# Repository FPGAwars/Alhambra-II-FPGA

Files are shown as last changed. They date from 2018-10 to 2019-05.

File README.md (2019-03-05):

# Alhambra II FPGA board
Open FPGA for makers

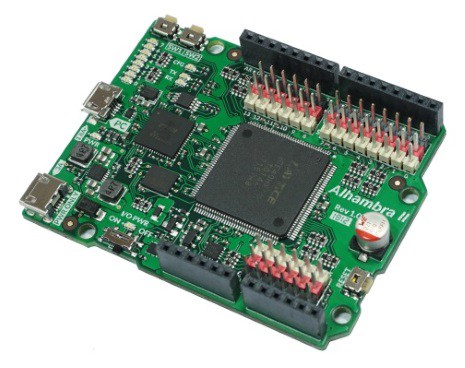
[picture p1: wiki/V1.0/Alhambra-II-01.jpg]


## Features

* iCE40HX4K (Lattice) FPGA development board (8K using opensource toolchain)
* Open hardware
* Compatible with the opensource [icestorm toolchain](Compatible with the opensource icestorm toolchain) and [Icestudio](https://github.com/FPGAwars/icestudio)
* Arduino like board: similar pinout than Arduino one
* You can Reuse most of available shields
* Control your robots / printbots from an FPGA
* FTDI 2232H USB device allows FPGA programming and UART interface to a PC
* ON/OFF electronic switch (turn off your mobile robot easily, switching on does not overload your USB port)
* 8 general purpose LEDs (user LEDs)
* 2 general purpose pushbuttons
* 32Mb flash memory for up to 30 bitstreams or user data
* 20 Input/output 3.3V (5V tolerant) pins
* All I/O pins include 200 ohms serial resistors for direct LED activation
* 4-Channels, 12 bits A/D converter
* Cold boot pins accessible from GPIO
* Switching regulators for high frequency processing at low power input
* 12 MHZ MEMS oscillator
* Reset pushbutton
* USB power supply, two connectors (up to 4.8A)
* Power pins and I/O pins allow permanent shortcircuit

## Documentation

[The proyect documentation is located in the wiki](https://github.com/FPGAwars/Alhambra-II-FPGA/wiki)

## Author

* [Eladio Delgado Mingorance](https://twitter.com/EladioDM)

## Credits

* Alhambra II V1.0 Board was derived from the [Icezum Alhambra V1.1 board](https://github.com/FPGAwars/icezum)

## License



Licensed under [Creative Commons Attribution-ShareAlike 4.0 International License](http://creativecommons.org/licenses/by-sa/4.0/)

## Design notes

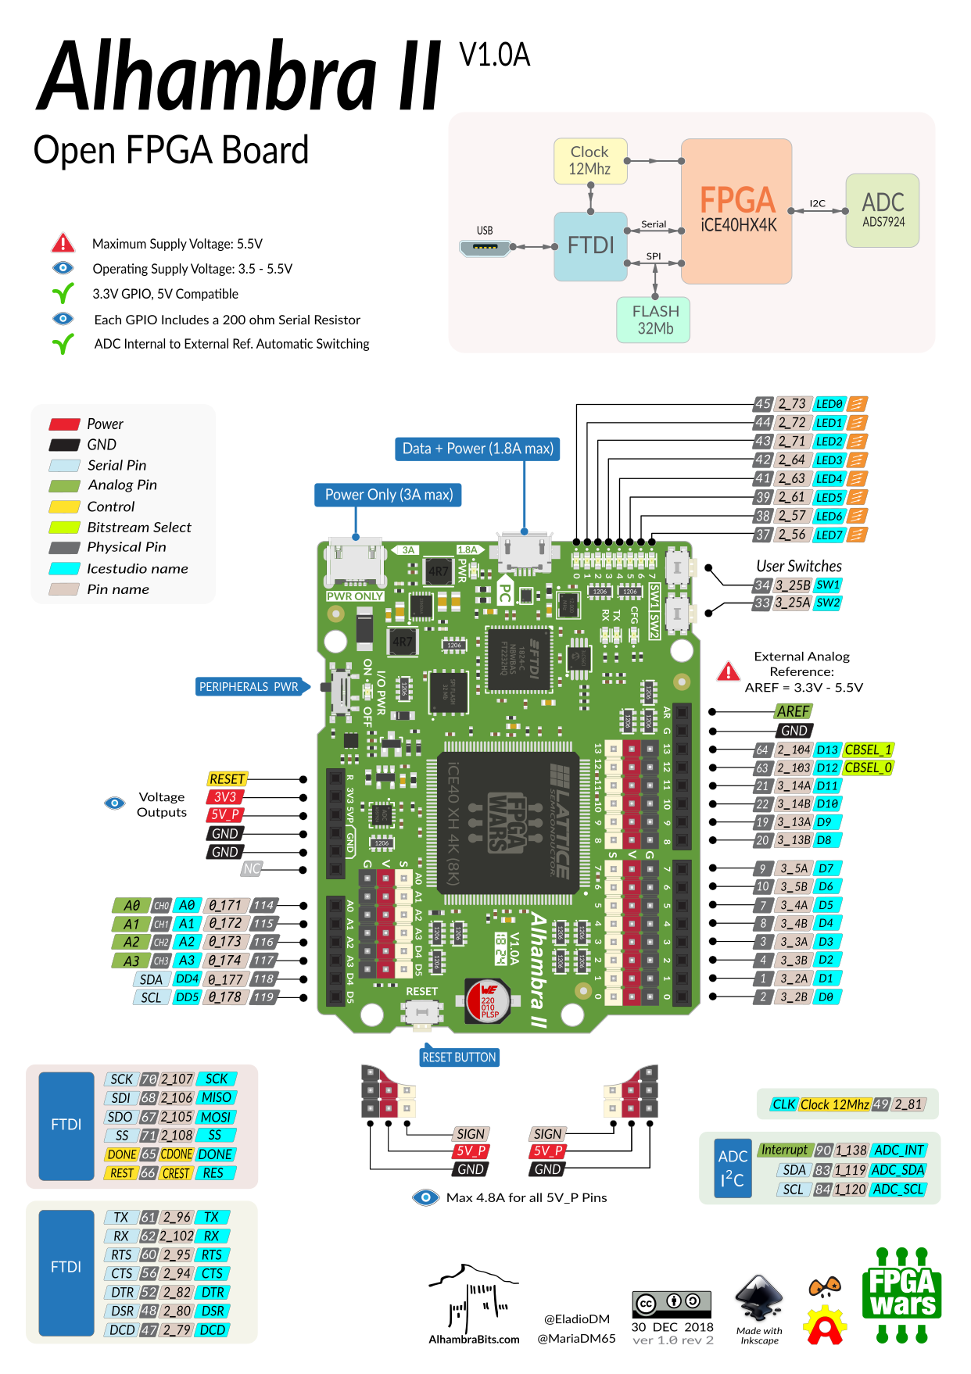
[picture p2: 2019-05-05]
doc/pinout/Alhambra II V1.0A - Pinout_v1.0_rev 2 - 150 dpi.png

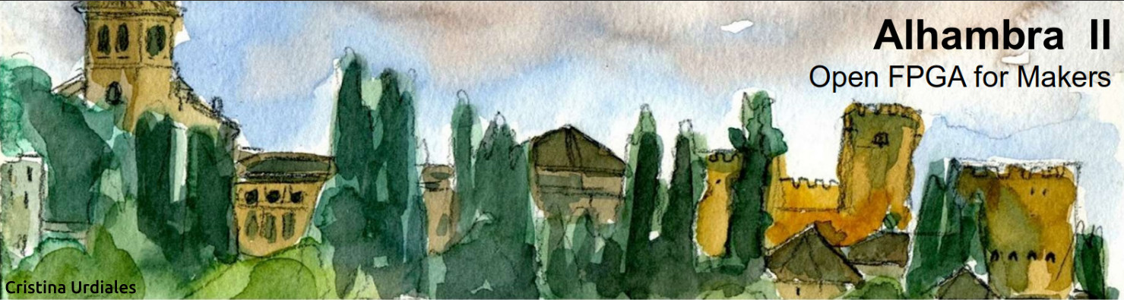
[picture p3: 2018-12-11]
wiki/V1.0/Alhambra-II-02.jpg

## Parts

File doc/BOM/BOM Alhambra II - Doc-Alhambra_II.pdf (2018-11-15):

BOM | Top Sheet
| Source Data From: | | Alhambra_II.PrjPcb
Project: | Alhambra_II.PrjPcb
PCB Version: | 1.0A
Variant: | None
Author: | Eladio Delgado Mingorance
Report Date: | 15/11/2018 9:33:17
Print Date: | 15-Nov-18 10:32:03 AM
# | Designator | Quantity | Description

1 | C1, C2, C4, C5, C7, C8, C9, C10, C11, C12, C13, C14, C15, C16, C17, C18, C20, C21, C22, C23, C25, C26, C27, C28, C29, C30, C32, C33, C34, C35, C36, C38, C39, C40, C46, C48, C49 | 37 | Capacitor SMD
2 3 | C3, C6, C19, C24, C31, C37, C43 | 7 | Capacitor SMD
| C41, C45, C47 | 3 | Capacitor SMD
4 5 | C42, C44 | 2 | Capacitor SMD
| C50 | 1 | Capacitor, Electrolytic, SMD
6 7 | D1, D5, D6 | 3 | Schottky Diode
| D2 | 1 | Protection, USB ESD
8 9 | D3 | 1 | Protection, Transient Suppression Diode
| D4 | 1 | Zener Diode
10 11 | FB1, FB2, FB3, FB4, FB5 | 5 | Ferrite Bead
| J1, J5 | 2 | Connector, 8 pin Socket Header 2.54mm
12 13 | J2, J6 | 2 | Connector, 6 pin Socket Header 2.54mm
| J3, J7 | 2 | Connector, 1x6 pin Header 2.54mm
14 15 | J4 | 1 | Connector, 1x8 pin Header 2.54mm
| J8, J12 | 2 | Connector, 1x6 pin Header 2.54mm
16 17 | J9, J13 | 2 | Connector, 1x6 pin Header 2.54mm
| J10 | 1 | Connector, 1x8 pin Header 2.54mm
18 19 | J11 | 1 | Connector, 1x8 pin Header 2.54mm
| J14 | 1 | Micro USB 2.0 SMT Type B Horizontal 5 Contacts WR-COM
20 21 | J15 | 1 | Micro USB 2.0 SMT Type B Horizontal 5 Contacts High Current WR-COM
| L1, L2 | 2 | Inductor SMD
22 23 | LD0, LD1, LD2, LD3, LD4, LD5, LD6, LD7, LD9 | 9 | LED
| LD8, LD10 | 2 | LED
24 25 | LD11, LD12 | 2 | LED
| Q1 | 1 | P-Channel MOSFET
26 27 | R1, R2, R19, R20, R21, R28, R29, R31, R32, R36, R37, R38, R39, R41, R42, R43 | 16 | Resistor, SMD
| R3, R23, R33, R47, R50 | 5 | Resistor, SMD
| R13, R30 | 11 | Resistor, Array 4x1
28 | R4, R5, R6, R7, R8, R9, R10, R11, R12,

29 | R14 | 1 | Resistor
30 31 | R15, R34, R35 | 3 | Resistor, Resistor, Array 4x1
| R16, R17, R25, R26, R27, R46 | 6 | Resistor, SMD
32 33 | R18, R22, R44, R45 | 4 | Resistor, SMD
| R24, R48, R49 | 3 | Resistor, SMD
34 35 | R40 | 1 | Resistor, SMD
| SW1, SW2, SW3 | 3 | Micro miniature pushbutton surface Switch
36 37 | SW4 | 1 | WS-SLSU 6.7x2.7 mm SMD Right Angled, boss design
| U1 | 1 | iCE40 HX4K Series FPGA Family, 3520 Logic Cells, 1.2 V Core, 80 K Embedded RAM Bits, 144-pin TQFP, Pb-Free, Tray
38 39 | U2 | 1 | NOR Flash Memory, serial
| U3 | 1 | Dual High Speed USB to Multipurpose UART/FIFO IC
40 41 | U4 | 1 | EEPROM, 2K Microwire Compatible Serial, 8 or 16 bit word size, 2.5-5.5 Vcc range
| U5 | 1 | Oscillator, Low-Power CMOS, 4 pin, 1.8-3.3V
42 43 | U6 | 1 | LDO Regulator, 5pin, SOT-23
| U7 | 1 | ADC Converter, 12-Bit, 4-Ch, I2C
44 45 | U8 | 1 | Dual Step-Down DC/DC converter 1A, 1.5 MHz
| U9 | 1 | Voltage supervisor, Reset active high, 200ms
Total Quantity | 155 | Notes

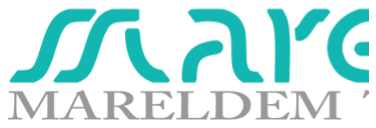
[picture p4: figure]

Value | Footprint | OrderingCode | Manufacturer
100nF ±10% 16V | C0402 | C0402C104K4RAC | Kemet
10uF ±10% 10V | C0603 | GRM188R61A106KE69D | Murata
10uF ±10% 10V | C0805_1.25_HD | LMK212ABJ106KG | Taiyo Yuden
100pF ±5% 25V | C0402 | 885012005046 | WE
220uF 10V | C_POL_6.3x5.8_WE | 875105244013 | WE
200mA 30V | SOD523 | RB520S30T1G | On Semiconductor
| SOT563 | 82400152 | Würth
| DO-214AC-SMA_Unidir | 824500500 | WE
3,6V | DO-219AC | PLZ3V6A | Vishay
330R 0,080R 1700 mA | L0603 | BLM18KG331SN1 | Murata
8 PIH | 1x8 Socket Header THT 2.54mm PIH | SSW-108-01-T-S | Samtec
6 PIH | 1x6 Socket Header THT 2.54mm PIH | SSW-106-01-T-S | Samtec
| 1x6 Pin Header 2.54 WHITE PIH | HTSW-106-07-T-S-NATURAL | Samtec
| 1x8 Pin Header 2.54 WHITE PIH | HTSW-108-07-T-S-NATURAL | Samtec
| 1x6 Pin Header 2.54 RED PIH | HTSW-106-07-T-S-RED | Samtec
| 1x6 Pin Header 2.54 BLACK PIH | HTSW-106-07-T-S-BLACK | Samtec
| 1x8 Pin Header 2.54 RED PIH | HTSW-108-07-T-S-RED | Samtec
| 1x8 Pin Header 2.54 BLACK PIH | HTSW-108-07-T-S-BLACK | Samtec
| 629105136821 | 629105136821 | WE
| 629105150521 | 629105150521 | WE
4,7uH 1,7A | 4018_WE_LQS_4R7 | 74404042047 | WE
Green | LED0603 | 150 060 VS7 5000 | WE
Yellow | LED0603 | 150 060 YS7 5000 | WE
Blue | LED0603 | 150 060 BS7 5000 | WE
| U-DFN2020-6 | DMP1005UFDF-7 | Diodes Incorporated
10k ±1% 0.063W | R0402 | CRCW040210K0FK | Vishay
1k ±5% 0.063W | R0402 | CRCW04021K00JN | Vishay
100R 5% 0,0625W, 100R ±5% 0,0625W | 4xArray_1206_Convex | YC164-JR-07100RL | Yageo

10K ±5% 0,0625W | 4xArray_1206_Convex | YC164-JR-0710KL | Yageo
470R ±5% 0,0625W, 470R 5% 0,0625W | 4xArray_1206_Convex | YC164-JR-07470RL | Yageo
100R ±5% 0.063W | R0402 | CRCW0402100RJN | Vishay
2k2 ±5% 0.063W | R0402 | CRCW04022K20JN | Vishay
12k ±1% 0.063W | R0402 | CRCW040212K0FK | Vishay
47k ±1% 0.063W | R0402 | CRCW040247K0FK | Vishay
| 4363x30458xx | 436353045816 | WE
| 450404015514 | 450404015514 | WE
| TQFP-144_HX4K_FPGAwars | iCE40HX4K-TQ144 | Lattice
32Mb | DFN-8 6x5mm | N25Q032A13EF640E | Micron
| FTDI_QFN-64 | FT2232HQ-REEL | FTDI
2Kb | MSOP8 | 93LC56CT-I/MS | Microchip
12MHz | OSC 3.2x2.5 | DSC1001CL2-012.0000 | Microchip
| SOT23-5_M | NCP114BSN330T1G | ON Semiconductor
| QFN16 | ADS7924IRTER | Texas Instruments
| WDFN_12_3x3 | PAM2306AYPKB | Diodes
2,93V | SOT23-3 | APX810-29SAG-7 | Diodes Incorporated

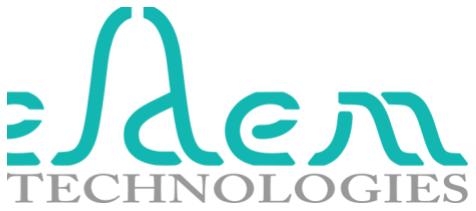
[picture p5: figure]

Supplier | Price (€) | Cost (€)
| 0,05 | 1,85
| 0,027 | 0,189
| 0,03 | 0,09
| 0,007 | 0,014
| 0,3 | 0,3
| 0,017 | 0,051
Würth | 0,1 | 0,1
| 0,108 | 0,108
| 0,07 | 0,07
| 0,021 | 0,105
Samtec | 0,438 | 0,876
Samtec | 0,381 | 0,762
Samtec | 0,26 | 0,52
Samtec | 0,35 | 0,35
Samtec | 0,26 | 0,52
Samtec | 0,26 | 0,52
Samtec | 0,35 | 0,35
Samtec | 0,35 | 0,35
WE | 0,26 | 0,26
WE | 0,58 | 0,58
WE | 0,128 | 0,256
| 0,07 | 0,63
| 0,07 | 0,14
| 0,09 | 0,18
| 0,16 | 0,16
| 0,006 | 0,096
| 0,003 | 0,015
| 0,006 | 0,066

0,006 | 0,006
| 0,006 | 0,018
| 0,003 | 0,018
| 0,003 | 0,012
| 0,006 | 0,018
| 0,006 | 0,006
WE | 0,2 | 0,6
WE | 0,27 | 0,27
| 6 | 6
Silica | 0,9 | 0,9
Silica | 3,45 | 3,45
Silica | 0,24 | 0,24
| 0,61 | 0,61
| 0,07 | 0,07
Silica | 1,35 | 1,35
RS | 0,32 | 0,32
Silica | 0,1 | 0,1
| Total Cost | 23,50

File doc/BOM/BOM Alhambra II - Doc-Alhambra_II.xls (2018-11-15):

 | BOM |  | Top Sheet
 | Source Data From: |  | Alhambra_II.PrjPcb
 | Project: |  | Alhambra_II.PrjPcb
 | PCB Version: |  | 1.0A
 | Variant: |  | None
 | Author: |  | Eladio Delgado Mingorance
 | Report Date: | 15/11/2018 | 9:33:17
 | Print Date: | 2018-11-15 | 9:35:09
# | Designator | Quantity | Description | Value | Footprint | OrderingCode | Manufacturer | Supplier | Price (€) | Cost (€)
1 | C1, C2, C4, C5, C7, C8, C9, C10, C11, C12, C13, C14, C15, C16, C17, C18, C20, C21, C22, C23, C25, C26, C27, C28, C29, C30, C32, C33, C34, C35, C36, C38, C39, C40, C46, C48, C49 | 37 | Capacitor SMD | 100nF ±10% 16V | C0402 | C0402C104K4RAC | Kemet |  | 0,05 | 1.85
2 | C3, C6, C19, C24, C31, C37, C43 | 7 | Capacitor SMD | 10uF ±10% 10V | C0603 | GRM188R61A106KE69D | Murata |  | 0,027 | 0.189
3 | C41, C45, C47 | 3 | Capacitor SMD | 10uF ±10% 10V | C0805_1.25_HD | LMK212ABJ106KG | Taiyo Yuden |  | 0,03 | 0.09
4 | C42, C44 | 2 | Capacitor SMD | 100pF ±5% 25V | C0402 | 885012005046 | WE |  | 0,007 | 0.014
5 | C50 | 1 | Capacitor, Electrolytic, SMD | 220uF 10V | C_POL_6.3x5.8_WE | 875105244013 | WE |  | 0,3 | 0.3
6 | D1, D5, D6 | 3 | Schottky Diode | 200mA 30V | SOD523 | RB520S30T1G | On Semiconductor |  | 0,017 | 0.051
7 | D2 | 1 | Protection, USB ESD |  | SOT563 | 82400152 | Würth | Würth | 0,1 | 0.1
8 | D3 | 1 | Protection, Transient Suppression Diode |  | DO-214AC-SMA_Unidir | 824500500 | WE |  | 0,108 | 0.108
9 | D4 | 1 | Zener Diode | 3,6V | DO-219AC | PLZ3V6A | Vishay |  | 0,07 | 0.07
10 | FB1, FB2, FB3, FB4, FB5 | 5 | Ferrite Bead | 330R 0,080R 1700 mA | L0603 | BLM18KG331SN1 | Murata |  | 0,021 | 0.105
11 | J1, J5 | 2 | Connector, 8 pin Socket Header 2.54mm | 8 PIH | 1x8 Socket Header THT 2.54mm PIH | SSW-108-01-T-S | Samtec | Samtec | 0,438 | 0.876
12 | J2, J6 | 2 | Connector, 6 pin Socket Header 2.54mm | 6 PIH | 1x6 Socket Header THT 2.54mm PIH | SSW-106-01-T-S | Samtec | Samtec | 0,381 | 0.762
13 | J3, J7 | 2 | Connector, 1x6 pin Header 2.54mm |  | 1x6 Pin Header 2.54 WHITE PIH | HTSW-106-07-T-S-NATURAL | Samtec | Samtec | 0,26 | 0.52
14 | J4 | 1 | Connector, 1x8 pin Header 2.54mm |  | 1x8 Pin Header 2.54 WHITE PIH | HTSW-108-07-T-S-NATURAL | Samtec | Samtec | 0,35 | 0.35
15 | J8, J12 | 2 | Connector, 1x6 pin Header 2.54mm |  | 1x6 Pin Header 2.54 RED PIH | HTSW-106-07-T-S-RED | Samtec | Samtec | 0,26 | 0.52
16 | J9, J13 | 2 | Connector, 1x6 pin Header 2.54mm |  | 1x6 Pin Header 2.54 BLACK PIH | HTSW-106-07-T-S-BLACK | Samtec | Samtec | 0,26 | 0.52
17 | J10 | 1 | Connector, 1x8 pin Header 2.54mm |  | 1x8 Pin Header 2.54 RED PIH | HTSW-108-07-T-S-RED | Samtec | Samtec | 0,35 | 0.35
18 | J11 | 1 | Connector, 1x8 pin Header 2.54mm |  | 1x8 Pin Header 2.54 BLACK PIH | HTSW-108-07-T-S-BLACK | Samtec | Samtec | 0,35 | 0.35
19 | J14 | 1 | Micro USB 2.0 SMT Type B Horizontal 5 Contacts WR-COM |  | 629105136821 | 629105136821 | WE | WE | 0,26 | 0.26
20 | J15 | 1 | Micro USB 2.0 SMT Type B Horizontal 5 Contacts High Current WR-COM |  | 629105150521 | 629105150521 | WE | WE | 0,58 | 0.58
21 | L1, L2 | 2 | Inductor SMD | 4,7uH 1,7A | 4018_WE_LQS_4R7 | 74404042047 | WE | WE | 0,128 | 0.256
22 | LD0, LD1, LD2, LD3, LD4, LD5, LD6, LD7, LD9 | 9 | LED | Green | LED0603 | 150 060 VS7 5000 | WE |  | 0,07 | 0.63
23 | LD8, LD10 | 2 | LED | Yellow | LED0603 | 150 060 YS7 5000 | WE |  | 0,07 | 0.14
24 | LD11, LD12 | 2 | LED | Blue | LED0603 | 150 060 BS7 5000 | WE |  | 0,09 | 0.18
25 | Q1 | 1 | P-Channel MOSFET |  | U-DFN2020-6 | DMP1005UFDF-7 | Diodes Incorporated |  | 0,16 | 0.16
26 | R1, R2, R19, R20, R21, R28, R29, R31, R32, R36, R37, R38, R39, R41, R42, R43 | 16 | Resistor, SMD | 10k ±1% 0.063W | R0402 | CRCW040210K0FK | Vishay |  | 0,006 | 0.096
27 | R3, R23, R33, R47, R50 | 5 | Resistor, SMD | 1k ±5% 0.063W | R0402 | CRCW04021K00JN | Vishay |  | 0,003 | 0.015
28 | R4, R5, R6, R7, R8, R9, R10, R11, R12, R13, R30 | 11 | Resistor, Array 4x1 | 100R 5% 0,0625W, 100R ±5% 0,0625W | 4xArray_1206_Convex | YC164-JR-07100RL | Yageo |  | 0,006 | 0.066
29 | R14 | 1 | Resistor | 10K ±5% 0,0625W | 4xArray_1206_Convex | YC164-JR-0710KL | Yageo |  | 0,006 | 0.006
30 | R15, R34, R35 | 3 | Resistor, Resistor, Array 4x1 | 470R ±5% 0,0625W, 470R 5% 0,0625W | 4xArray_1206_Convex | YC164-JR-07470RL | Yageo |  | 0,006 | 0.018
31 | R16, R17, R25, R26, R27, R46 | 6 | Resistor, SMD | 100R ±5% 0.063W | R0402 | CRCW0402100RJN | Vishay |  | 0,003 | 0.018
32 | R18, R22, R44, R45 | 4 | Resistor, SMD | 2k2 ±5% 0.063W | R0402 | CRCW04022K20JN | Vishay |  | 0,003 | 0.012
33 | R24, R48, R49 | 3 | Resistor, SMD | 12k ±1% 0.063W | R0402 | CRCW040212K0FK | Vishay |  | 0,006 | 0.018
34 | R40 | 1 | Resistor, SMD | 47k ±1% 0.063W | R0402 | CRCW040247K0FK | Vishay |  | 0,006 | 0.006
35 | SW1, SW2, SW3 | 3 | Micro miniature pushbutton surface Switch |  | 4363x30458xx | 436353045816 | WE | WE | 0,2 | 0.6
36 | SW4 | 1 | WS-SLSU 6.7x2.7 mm SMD Right Angled, boss design |  | 450404015514 | 450404015514 | WE | WE | 0,27 | 0.27
37 | U1 | 1 | iCE40 HX4K Series FPGA Family, 3520 Logic Cells, 1.2 V Core, 80 K Embedded RAM Bits, 144-pin TQFP, Pb-Free, Tray |  | TQFP-144_HX4K_FPGAwars | iCE40HX4K-TQ144 | Lattice |  | 6 | 6
38 | U2 | 1 | NOR Flash Memory, serial | 32Mb | DFN-8 6x5mm | N25Q032A13EF640E | Micron | Silica | 0,9 | 0.9
39 | U3 | 1 | Dual High Speed USB to Multipurpose UART/FIFO IC |  | FTDI_QFN-64 | FT2232HQ-REEL | FTDI | Silica | 3,45 | 3.45
40 | U4 | 1 | EEPROM, 2K Microwire Compatible Serial, 8 or 16 bit word size, 2.5-5.5 Vcc range | 2Kb | MSOP8 | 93LC56CT-I/MS | Microchip | Silica | 0,24 | 0.24
41 | U5 | 1 | Oscillator, Low-Power CMOS, 4 pin, 1.8-3.3V | 12MHz | OSC 3.2x2.5 | DSC1001CL2-012.0000 | Microchip |  | 0,61 | 0.61
42 | U6 | 1 | LDO Regulator, 5pin, SOT-23 |  | SOT23-5_M | NCP114BSN330T1G | ON Semiconductor |  | 0,07 | 0.07
43 | U7 | 1 | ADC Converter, 12-Bit, 4-Ch, I2C |  | QFN16 | ADS7924IRTER | Texas Instruments | Silica | 1,35 | 1.35
44 | U8 | 1 | Dual Step-Down DC/DC converter 1A, 1.5 MHz |  | WDFN_12_3x3 | PAM2306AYPKB | Diodes | RS | 0,32 | 0.32
45 | U9 | 1 | Voltage supervisor, Reset active high, 200ms | 2,93V | SOT23-3 | APX810-29SAG-7 | Diodes Incorporated | Silica | 0,1 | 0.1
 | Total Quantity | 155 | Notes |  |  |  |  |  | Total Cost | 23.50

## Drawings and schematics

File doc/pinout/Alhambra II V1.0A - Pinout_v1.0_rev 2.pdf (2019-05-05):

# Alhambra II

# FTDI

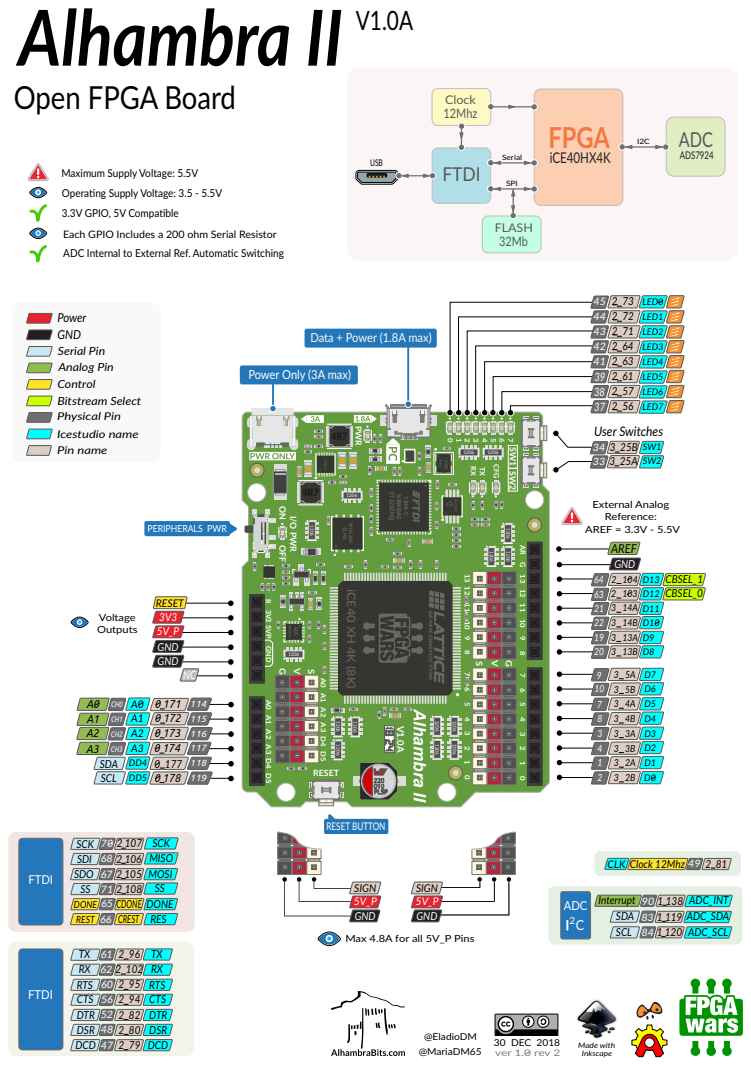
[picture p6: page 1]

Maximum Supply Voltage: 5.5V
Operang Supply Voltage: 3.5 - 5.5V
3.3V GPIO, 5V Compable
Each GPIO Includes a 200 ohm Serial Resistor
ADC Internal to External Ref. Automac Switching

Max 4.8A for all 5V_P Pins

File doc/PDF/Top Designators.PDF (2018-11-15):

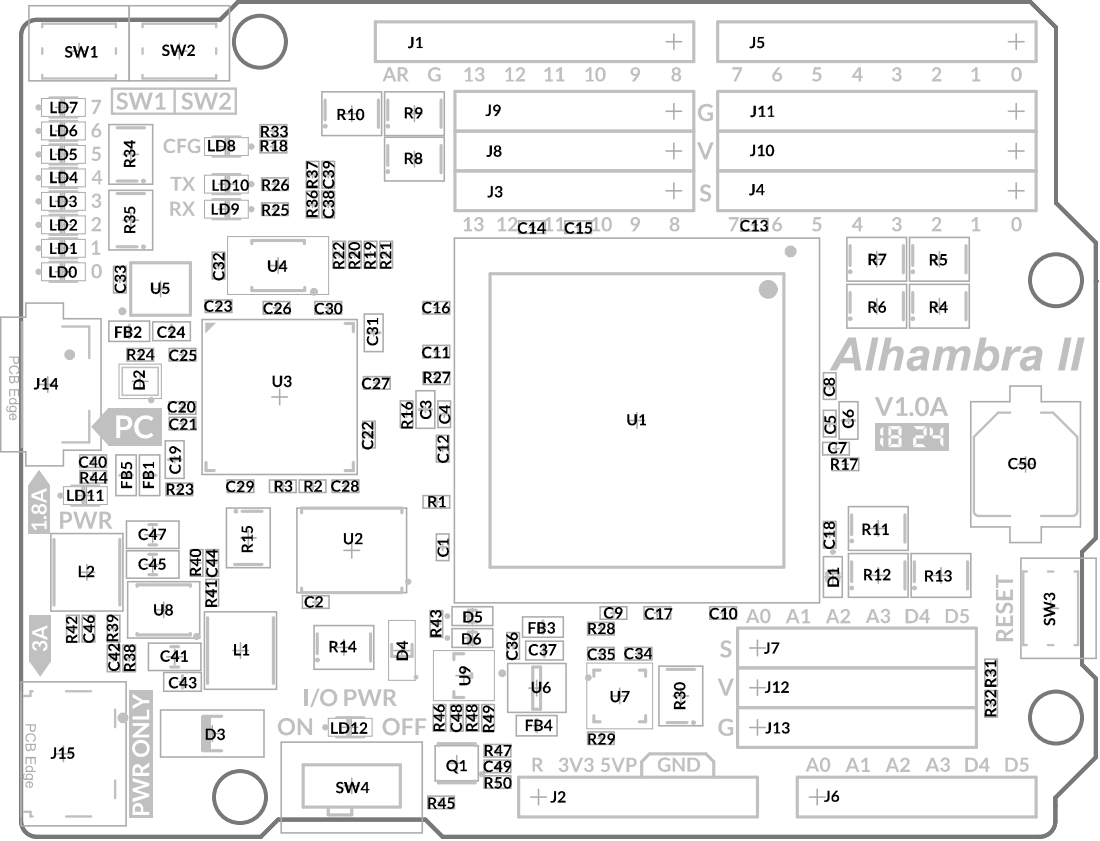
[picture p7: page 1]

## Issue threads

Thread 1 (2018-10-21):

Firmware update/upload (FPGArduino)

drtrigon, 2018-10-21:
As mentioned in https://github.com/cliffordwolf/picorv32/issues/92; "The firmware should be uploaded in the flash memory using iceprog, outside of icestudio. In future versión we will integrate it into icestudio as well".

What about support for FPGArduino (see http://www.nxlab.fer.hr/fpgarduino/)? That would allow to compile and upload code via Arduino IDE:
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

drtrigon, 2018-10-28:
https://github.com/f32c/arduino/issues/32

Closed 2018-10-28.

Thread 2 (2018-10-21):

Enable 32 bit GPIO input

drtrigon, 2018-10-21:
Based on https://github.com/cliffordwolf/picorv32/issues/92 I enhanced the design to 32 output pins as shown here (renamed leds[7:0] to outp[31:0]):
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
How to add a control register that allows to switch single bits from output to input? How to add input pin functionality?

drtrigon, 2018-10-28:
See https://github.com/cliffordwolf/picorv32/issues/96#issuecomment-433698391.

> May be you can integrate this example into the repo as well in order to be helpful to others too?
>
> However one question remains; Can you explain to me how to use the tri-state block? I placed and wired it - verification was ok but no bitstream could be generated, the result was an error.

Closed 2018-10-28.

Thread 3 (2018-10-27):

Alhambra ADC example

drtrigon, 2018-10-27:
Is an ADC example for Alhambra 2 available? May be one using picorv32?

I only found one for "MCP300x A/D controller (SPI master)" but as I understand is this the wrong chip and interface (SPI instead of I2C).

drtrigon, 2018-10-31:
Icezum Alhambra ADC: https://groups.google.com/forum/m/#!topic/fpga-wars-explorando-el-lado-libre/4_vHakcwXdQ

https://github.com/kaibran/printbot

Obijuan, 2018-10-31:
You can find a simple example here:

https://github.com/Obijuan/CTIF-Madrid-2018-FPGAs-Libres/tree/master/Colecciones/CTIF-MadridCap-6/examples/03-ADC

It just reads the AD channel 0 and show its value in the leds, at rate of 4Hz. The example is for the Alhambra I board, but the connection for the Alhambra II are the same

i am attaching here the example for the Alhambra II board

I am in the process of documenting everything. But in the meanwhile that example may help a little bit. The Alhambra II ADC converter is connected to the FPGA by the I2C bus

[05-adc0-leds.zip](https://github.com/FPGAwars/Alhambra-II-FPGA/files/2535521/05-adc0-leds.zip)

drtrigon, 2018-10-31:
Thanks a lot! That is very helpful!

(Now have to merge picorv32 with this... ;))

drtrigon, 2018-11-03:
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

Closed 2018-10-31.

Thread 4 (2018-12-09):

Enhance specification with minimal power consumption

drtrigon, 2018-12-09:
I would like to know the minimal power consumption of the board an how I can minimize it. I did a very simple fast measurement and got around 60 to 70mA (with 4 LEDs on). Does that sound realistic?

I read that the TinyFPGA board goes down to "1.3 mA power when active", see https://www.crowdsupply.com/tinyfpga/tinyfpga-bx. Any chance that Alhambra 2 comes anywhere close to this?

EladioDM, 2018-12-10:
The 1.3 mA you mention refers to the oscillator only. Just the power LED may doubles that consumption. Anyway the static consumption of the whole board doesn´t go much higher, the FPGA and flash memory static current is under one milliamp.

In the Alhambra II, most of the power consumption comes from the peripherals around the FPGA. With 4 user LEDs and power LED on, peripherals power switch off and simple low freq circuit configured in the FPGA (like the demo bit stream), the Alhambra II draws about 35 mA: FTDI draws about 15 mA and LEDs 2.5 mA/LED. The remaining 10 mA goes to the ADC, the oscillator and the switching DCDC converter losses.

As you can see the board is not designed for low power but for ease to use and quick start up, with minimal or no addtional hardware.

May be it is not your case if you are pointing to low power applications, but consider it could be the opposite if you put the FPGA to work: Current drawn by the TinyFPGA using linear regulators could become higher than that drawn by the Alhambra II powered by switching regulators.

drtrigon, 2021-11-04:
Thanks for the detailed info!

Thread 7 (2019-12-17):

Wrong voltage regulator

gusmanb, 2019-12-17:
In the schematic (at least on the PDF) the specified regulator is the PAM2306AYPKB which is the 3.3/1.2 fixed one but the circuit is for the adjustable one, PAM2306AYPAA.

Reference or schema must be updated.

Cheers.

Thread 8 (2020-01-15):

Distance between pins 7 and 8

cesarab, 2020-01-15:
Hi.

Is there any reason why the distance between GPIO pins 7 and 8 is not multiple of 100 mils (2.54 mm)?

I wanted to create a hat for the FPGA, out of a regular perfboard, but it doesn't fit because of that.

The other side of the board does maintain the correct distance.

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

cesarab, 2020-01-15:
Nevermind. I can see that arduino has the same distance and this card keeps the Arduino form factor, so I gues that's the answer to my question.

Obijuan, 2020-01-16:
Yes, that is the reason: keeping the board compatible with Arduino Uno. All
the shields for the Arduino Uno can be used with the Alhambra II board

El mié., 15 ene. 2020 22:47, César Abreu <notifications@github.com>
escribió:

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

Closed 2020-01-15.

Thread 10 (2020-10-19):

Speed-up memory access with PLL?

drtrigon, 2020-10-19:
I was working on https://github.com/drtrigon/fpgarduino-icestorm an have setup a picorv32 with peripherials in order to emulate/mimic an arduino uno board. During this I came to the point where I would have to implement `delayMicroseconds()` which is not possible due to the slow memory access.

Is it possible to speed up the SPI memory access, by making the clock faster using e.g. a PLL? Does a PLL block exist for icestudio? Does it work with the Alhambra II board?

drtrigon, 2020-10-26:
@Obijuan and @Jesus89 do you see a way of speeding-up SPI memory access (e.g. using a PLL)?

jcmadrioso, 2021-04-17:
I have been using PLL for speeding up clock, but only with icestorm. I'm trying to use it in IceStudio via module instantiation.

drtrigon, 2021-11-04:
@jcmadrioso: Can you share the code?

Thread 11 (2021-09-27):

VHDL Support

pedro-javierf, 2021-09-27:
I was wondering what learning resources are available regarding the programming of the iCE40HX4K in the Alhambra-II using the VHDL language rather than Verilog/SystemVerilog. The reasoning for this is, lots of Spanish universities teach VHDL and not Verilog, thus it'd be great for students to be able to leverage their learnt FPGA skills using this board.

As far as I'm concerned, the only toolchain that supports this is the "official" Lattice iCEcube2. But how can a bitmap generated with this privative software (or others) be programmed into the board over USB?

Werni2A, 2021-11-27:
Shouldn't Lattice's toolchain be able to also program the Alhambra Board? I can't imagine that this does not work. Anyhow an open-source approach is provided by iceprog from the [icestorm](https://github.com/YosysHQ/icestorm) or [openFPGAloader](https://github.com/trabucayre/openFPGALoader).

A short example below shows how to use both tools to program the ice40 FPGA (both were tested on my board). Still you have to adjust `PWD` for your current working directory and `PROJ` with your bitstream project name.

```
DOCKERARGS=run --rm -v /$(PWD)://wrk -w //wrk
ICEPROG=docker $(DOCKERARGS) --device /dev/bus/usb gcr.io/hdl-containers/prog:latest iceprog
OPENFPGALOADER=docker $(DOCKERARGS) --device /dev/bus/usb gcr.io/hdl-containers/openfpgaloader:latest openFPGALoader

$(ICEPROG) -d i:0x0403:0x6010:0 build/$(PROJ).bin
$(OPENFPGALOADER) -b ice40_generic build/$(PROJ).bin
```

Werni2A, 2021-11-28:
A simple design can be found at [my repo](https://github.com/Werni2A/Valhalla-II) that should get you started with a pure OSS VHDL flow.

pedro-javierf, 2021-11-28:
Thanks for the OSS flow @Werni2A ! I will definitely look into it. I had already found and documented the lattice VHDL flow [here ](https://pedrojavier.com/2021/10/11/tutorial-how-to-use-vhdl-with-the-alhambra-ii-fpga/) but this is what I really wanted :)

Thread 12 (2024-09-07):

Suggestion for the wiki - list software packages by recommendation order.

zapta, 2024-09-07:
The Feature section at https://github.com/FPGAwars/Alhambra-II-FPGA/wiki lists:

*  Compatible with the opensource [icestorm toolchain](Compatible with the opensource icestorm toolchain) and [Icestudio](https://github.com/FPGAwars/icestudio)

I suggest to list the software system in recommendation order.  E.g.:

* Compatible with the open source design tools  icestudio [link] (a graphical circuit builder), apio [link]  (an easy to use command line framework), and the icestorm toolhain [link] (core tools for advanced users).

This will convey the recommended path to users.

My 2c.

zapta, 2025-05-15:
Dropping this one.

Closed 2025-05-15.

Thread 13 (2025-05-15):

Please program the 'serial code' field of the Alhambra-ii boards you ship

zapta, 2025-05-15:
Following is the output of ``openFPGALoader --list`` with two FPGA boards, alhambra-ii and upduino.  Notice that the alhambra doesn't have the serial code programed in the expected field while the upduino does.  Thsi field allows the openFPGALoder programmer to distinguish between multiple similar boards that are connected to the host.

This will also allow apio to distinguish between boards when programming using openFPGALoader:  ``apio upload --serial FT94RQ8V``.

```
Bus device vid:pid       probe type      manufacturer serial               product
000 001    0x0403:0x6010 FTDI2232        AlhambraBits none                 Alhambra II v1.0A - B09-335
001 001    0x0403:0x6010 FTDI2232        tinyVision   FT94RQ8V             UPduino v3.1c
```

@cavearr, FYI, related to https://github.com/FPGAwars/apio/issues/596

cavearr, 2025-05-15:
Very interesting @zapta ! i'm reply you at the other issue

cavearr, 2025-05-15:
@zapta ,Apparently I was mistaken, and openfpgaloader doesn't save to SRAM; it actually tries and ends up saving to flash. It appeared as Not Tested in the documentation, and my initial tests gave me the impression that it worked.

Sorry for the misunderstanding. I'll investigate what you're saying to see if we can find a solution.

In any case, using openfpgaloader now or in the future is more than promising.

cavearr, 2025-05-15:
yes!, i'll talking with them now., tell you soon

@zapta

zapta, 2025-05-18:
Hi @cavearr, the new ``apio drivers list ftdi`` command now prints also the serial number field so I don't think it's necessary anymore to include the board's serial number (``B09-335`` in the example below) in the product description field.

```
$ apio drivers list ftdi

┌──────────┬───────────────┬─────────────────────────────┬──────┬──────┬──────────┬─────┬────────┐
│ TYPE     │ MANUFACTURER  │ DESCRIPTION                 │ VID  │ PID  │ SERIAL   │ BUS │ DEVICE │
├──────────┼───────────────┼─────────────────────────────┼──────┼──────┼──────────┼─────┼────────┤
│ FTDI2232 │ tinyVision.ai │ UPduino v3.1c               │ 0403 │ 6010 │ FT94RQ8V │  1  │   1    │
├──────────┼───────────────┼─────────────────────────────┼──────┼──────┼──────────┼─────┼────────┤
│ FTDI2232 │ AlhambraBits  │ Alhambra II v1.0A - B09-335 │ 0403 │ 6010 │          │  0  │   1    │
└──────────┴───────────────┴─────────────────────────────┴──────┴──────┴──────────┴─────┴────────┘
Found 2 devices
```

cavearr, 2025-05-18:
Hi @zapta ! i'm talking with Alhambrabits about it and they listen to us. This week they send us an ftdi template to test it an if it works they put in all of new Alhambra boards.

I'm exploring ftdi in deep to look for a solution and other fpga friend give me a possible solution, i'm testing it and tell you in the next days.

zapta, 2025-05-18:
Thanks @cavearr, that will be very useful.  I don't know if its possible but it if the FTDI chips come from FTDI with a serial number, it would be nice to leave that number as is.

zapta, 2025-05-19:
@cavearr, here is another motivation for having standard serial number for Alhambra, when Mac OSX maps FTDI channels to serial ports, it includes the serial number in the port name if available, for example ``/dev/cu.usbserial-FT94RQ8V0`` for serial number ``FT94RQ8V``. This provides one more way to distinguish between devices if more than one if connected.

```
$ apio drivers list serial

SERIAL Devices                                                                                 
┌───────────────┬─────────────────────────────┬──────┬──────┬────────────┬─────────────────────────────┐
│ MANUFACTURER  │ DESCRIPTION                 │ VID  │ PID  │ SERIAL-NUM │ PORT                        │
├───────────────┼─────────────────────────────┼──────┼──────┼────────────┼─────────────────────────────┤
│ tinyVision.ai │ UPduino v3.1c               │ 0403 │ 6010 │ FT94RQ8V   │ /dev/cu.usbserial-FT94RQ8V0 │
├───────────────┼─────────────────────────────┼──────┼──────┼────────────┼─────────────────────────────┤
│ tinyVision.ai │ UPduino v3.1c               │ 0403 │ 6010 │ FT94RQ8V   │ /dev/cu.usbserial-FT94RQ8V1 │
├───────────────┼─────────────────────────────┼──────┼──────┼────────────┼─────────────────────────────┤
│ AlhambraBits  │ Alhambra II v1.0A - B09-335 │ 0403 │ 6010 │            │ /dev/cu.usbserial-1201      │
├───────────────┼─────────────────────────────┼──────┼──────┼────────────┼─────────────────────────────┤
│ AlhambraBits  │ Alhambra II v1.0A - B09-335 │ 0403 │ 6010 │            │ /dev/cu.usbserial-1200      │
└───────────────┴─────────────────────────────┴──────┴──────┴────────────┴─────────────────────────────┘
Found 4 devices
```

cavearr, 2025-05-21:
Fantastic @zapta!, I'm waiting for Alhambrabits to send me the Eprom programming templates and I'm investigating how to change it with a small tool of ours. As soon as I have all the info and consolidate it, I'll share it with you.

zapta, 2025-05-21:
@cavearr, FYI, according to the ftdi standard programming tool, the total size of manufacturer, product, and serial string should be <= 46, and max serial number length is 16.

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

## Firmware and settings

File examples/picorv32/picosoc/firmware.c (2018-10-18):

/*
 *  PicoSoC - A simple example SoC using PicoRV32
 *
 *  Copyright (C) 2017  Clifford Wolf <clifford@clifford.at>
 *
 *  Permission to use, copy, modify, and/or distribute this software for any
 *  purpose with or without fee is hereby granted, provided that the above
 *  copyright notice and this permission notice appear in all copies.
 *
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
 */

#include <stdint.h>
#include <stdbool.h>

#if !defined(ICEBREAKER) && !defined(HX8KDEMO)
#  error "Set -DICEBREAKER or -DHX8KDEMO when compiling firmware.c"
#endif

// a pointer to this is a null pointer, but the compiler does not
// know that because "sram" is a linker symbol from sections.lds.
extern uint32_t sram;

#define reg_spictrl (*(volatile uint32_t*)0x02000000)
#define reg_uart_clkdiv (*(volatile uint32_t*)0x02000004)
#define reg_uart_data (*(volatile uint32_t*)0x02000008)
#define reg_leds (*(volatile uint32_t*)0x03000000)

// --------------------------------------------------------

extern uint32_t flashio_worker_begin;
extern uint32_t flashio_worker_end;

void flashio(uint8_t *data, int len, uint8_t wrencmd)
{
	uint32_t func[&flashio_worker_end - &flashio_worker_begin];

	uint32_t *src_ptr = &flashio_worker_begin;
	uint32_t *dst_ptr = func;

	while (src_ptr != &flashio_worker_end)
		*(dst_ptr++) = *(src_ptr++);

	((void(*)(uint8_t*, uint32_t, uint32_t))func)(data, len, wrencmd);
}

#ifdef HX8KDEMO
void set_flash_qspi_flag()
{
	uint8_t buffer[8];
	uint32_t addr_cr1v = 0x800002;

	// Read Any Register (RDAR 65h)
	buffer[0] = 0x65;
	buffer[1] = addr_cr1v >> 16;
	buffer[2] = addr_cr1v >> 8;
	buffer[3] = addr_cr1v;
	buffer[4] = 0; // dummy
	buffer[5] = 0; // rdata
	flashio(buffer, 6, 0);
	uint8_t cr1v = buffer[5];

	// Write Enable (WREN 06h) + Write Any Register (WRAR 71h)
	buffer[0] = 0x71;
	buffer[1] = addr_cr1v >> 16;
	buffer[2] = addr_cr1v >> 8;
	buffer[3] = addr_cr1v;
	buffer[4] = cr1v | 2; // Enable QSPI
	flashio(buffer, 5, 0x06);
}

void set_flash_latency(uint8_t value)
{
	reg_spictrl = (reg_spictrl & ~0x007f0000) | ((value & 15) << 16);

	uint32_t addr = 0x800004;
	uint8_t buffer_wr[5] = {0x71, addr >> 16, addr >> 8, addr, 0x70 | value};
	flashio(buffer_wr, 5, 0x06);
}

void set_flash_mode_spi()
{
	reg_spictrl = (reg_spictrl & ~0x00700000) | 0x00000000;
}

void set_flash_mode_dual()
{
	reg_spictrl = (reg_spictrl & ~0x00700000) | 0x00400000;
}

void set_flash_mode_quad()
{
	reg_spictrl = (reg_spictrl & ~0x00700000) | 0x00200000;
}

void set_flash_mode_qddr()
{
	reg_spictrl = (reg_spictrl & ~0x00700000) | 0x00600000;
}
#endif

#ifdef ICEBREAKER
void set_flash_qspi_flag()
{
	uint8_t buffer[8];

	// Read Configuration Registers (RDCR1 35h)
	buffer[0] = 0x35;
	buffer[1] = 0x00; // rdata
	flashio(buffer, 2, 0);
	uint8_t sr2 = buffer[1];

	// Write Enable Volatile (50h) + Write Status Register 2 (31h)
	buffer[0] = 0x31;
	buffer[1] = sr2 | 2; // Enable QSPI
	flashio(buffer, 2, 0x50);
}

void set_flash_mode_spi()
{
	reg_spictrl = (reg_spictrl & ~0x007f0000) | 0x00000000;
}

void set_flash_mode_dual()
{
	reg_spictrl = (reg_spictrl & ~0x007f0000) | 0x00400000;
}

void set_flash_mode_quad()
{
	reg_spictrl = (reg_spictrl & ~0x007f0000) | 0x00240000;
}

void set_flash_mode_qddr()
{
	reg_spictrl = (reg_spictrl & ~0x007f0000) | 0x00670000;
}

void enable_flash_crm()
{
	reg_spictrl |= 0x00100000;
}
#endif

// --------------------------------------------------------

void putchar(char c)
{
	if (c == '\n')
		putchar('\r');
	reg_uart_data = c;
}

void print(const char *p)
{
	while (*p)
		putchar(*(p++));
}

void print_hex(uint32_t v, int digits)
{
	for (int i = 7; i >= 0; i--) {
		char c = "0123456789abcdef"[(v >> (4*i)) & 15];
		if (c == '0' && i >= digits) continue;
		putchar(c);
		digits = i;
	}
}

void print_dec(uint32_t v)
{
	if (v >= 100) {
		print(">=100");
		return;
	}

	if      (v >= 90) { putchar('9'); v -= 90; }
	else if (v >= 80) { putchar('8'); v -= 80; }
	else if (v >= 70) { putchar('7'); v -= 70; }
	else if (v >= 60) { putchar('6'); v -= 60; }
	else if (v >= 50) { putchar('5'); v -= 50; }
	else if (v >= 40) { putchar('4'); v -= 40; }
	else if (v >= 30) { putchar('3'); v -= 30; }
	else if (v >= 20) { putchar('2'); v -= 20; }
	else if (v >= 10) { putchar('1'); v -= 10; }

	if      (v >= 9) { putchar('9'); v -= 9; }
	else if (v >= 8) { putchar('8'); v -= 8; }
	else if (v >= 7) { putchar('7'); v -= 7; }
	else if (v >= 6) { putchar('6'); v -= 6; }
	else if (v >= 5) { putchar('5'); v -= 5; }
	else if (v >= 4) { putchar('4'); v -= 4; }
	else if (v >= 3) { putchar('3'); v -= 3; }
	else if (v >= 2) { putchar('2'); v -= 2; }
	else if (v >= 1) { putchar('1'); v -= 1; }
	else putchar('0');
}

char getchar_prompt(char *prompt)
{
	int32_t c = -1;

	uint32_t cycles_begin, cycles_now, cycles;
	__asm__ volatile ("rdcycle %0" : "=r"(cycles_begin));

	reg_leds = ~0;

	if (prompt)
		print(prompt);

	while (c == -1) {
		__asm__ volatile ("rdcycle %0" : "=r"(cycles_now));
		cycles = cycles_now - cycles_begin;
		if (cycles > 12000000) {
			if (prompt)
				print(prompt);
			cycles_begin = cycles_now;
			reg_leds = ~reg_leds;
		}
		c = reg_uart_data;
	}

	reg_leds = 0;
	return c;
}

char getchar()
{
	return getchar_prompt(0);
}

// --------------------------------------------------------

void cmd_read_flash_id()
{
	uint8_t buffer[17] = { 0x9F, /* zeros */ };
	flashio(buffer, 17, 0);

	for (int i = 1; i <= 16; i++) {
		putchar(' ');
		print_hex(buffer[i], 2);
	}
	putchar('\n');
}

// --------------------------------------------------------

#ifdef HX8KDEMO
uint8_t cmd_read_flash_regs_print(uint32_t addr, const char *name)
{
	set_flash_latency(8);

	uint8_t buffer[6] = {0x65, addr >> 16, addr >> 8, addr, 0, 0};
	flashio(buffer, 6, 0);

	print("0x");
	print_hex(addr, 6);
	print(" ");
	print(name);
	print(" 0x");
	print_hex(buffer[5], 2);
	print("\n");

	return buffer[5];
}

void cmd_read_flash_regs()
{
	print("\n");
	uint8_t sr1v = cmd_read_flash_regs_print(0x800000, "SR1V");
	uint8_t sr2v = cmd_read_flash_regs_print(0x800001, "SR2V");
	uint8_t cr1v = cmd_read_flash_regs_print(0x800002, "CR1V");
	uint8_t cr2v = cmd_read_flash_regs_print(0x800003, "CR2V");
	uint8_t cr3v = cmd_read_flash_regs_print(0x800004, "CR3V");
	uint8_t vdlp = cmd_read_flash_regs_print(0x800005, "VDLP");
}
#endif

#ifdef ICEBREAKER
uint8_t cmd_read_flash_reg(uint8_t cmd)
{
	uint8_t buffer[2] = {cmd, 0};
	flashio(buffer, 2, 0);
	return buffer[1];
}

void print_reg_bit(int val, const char *name)
{
	for (int i = 0; i < 12; i++) {
		if (*name == 0)
			putchar(' ');
		else
			putchar(*(name++));
	}

	putchar(val ? '1' : '0');
	putchar('\n');
}

void cmd_read_flash_regs()
{
	putchar('\n');

	uint8_t sr1 = cmd_read_flash_reg(0x05);
	uint8_t sr2 = cmd_read_flash_reg(0x35);
	uint8_t sr3 = cmd_read_flash_reg(0x15);

	print_reg_bit(sr1 & 0x01, "S0  (BUSY)");
	print_reg_bit(sr1 & 0x02, "S1  (WEL)");
	print_reg_bit(sr1 & 0x04, "S2  (BP0)");
	print_reg_bit(sr1 & 0x08, "S3  (BP1)");
	print_reg_bit(sr1 & 0x10, "S4  (BP2)");
	print_reg_bit(sr1 & 0x20, "S5  (TB)");
	print_reg_bit(sr1 & 0x40, "S6  (SEC)");
	print_reg_bit(sr1 & 0x80, "S7  (SRP)");
	putchar('\n');

	print_reg_bit(sr2 & 0x01, "S8  (SRL)");
	print_reg_bit(sr2 & 0x02, "S9  (QE)");
	print_reg_bit(sr2 & 0x04, "S10 ----");
	print_reg_bit(sr2 & 0x08, "S11 (LB1)");
	print_reg_bit(sr2 & 0x10, "S12 (LB2)");
	print_reg_bit(sr2 & 0x20, "S13 (LB3)");
	print_reg_bit(sr2 & 0x40, "S14 (CMP)");
	print_reg_bit(sr2 & 0x80, "S15 (SUS)");
	putchar('\n');

	print_reg_bit(sr3 & 0x01, "S16 ----");
	print_reg_bit(sr3 & 0x02, "S17 ----");
	print_reg_bit(sr3 & 0x04, "S18 (WPS)");
	print_reg_bit(sr3 & 0x08, "S19 ----");
	print_reg_bit(sr3 & 0x10, "S20 ----");
	print_reg_bit(sr3 & 0x20, "S21 (DRV0)");
	print_reg_bit(sr3 & 0x40, "S22 (DRV1)");
	print_reg_bit(sr3 & 0x80, "S23 (HOLD)");
	putchar('\n');
}
#endif

// --------------------------------------------------------

uint32_t cmd_benchmark(bool verbose, uint32_t *instns_p)
{
	uint8_t data[256];
	uint32_t *words = (void*)data;

	uint32_t x32 = 314159265;

	uint32_t cycles_begin, cycles_end;
	uint32_t instns_begin, instns_end;
	__asm__ volatile ("rdcycle %0" : "=r"(cycles_begin));
	__asm__ volatile ("rdinstret %0" : "=r"(instns_begin));

	for (int i = 0; i < 20; i++)
	{
		for (int k = 0; k < 256; k++)
		{
			x32 ^= x32 << 13;
			x32 ^= x32 >> 17;
			x32 ^= x32 << 5;
			data[k] = x32;
		}

		for (int k = 0, p = 0; k < 256; k++)
		{
			if (data[k])
				data[p++] = k;
		}

		for (int k = 0, p = 0; k < 64; k++)
		{
			x32 = x32 ^ words[k];
		}
	}

	__asm__ volatile ("rdcycle %0" : "=r"(cycles_end));
	__asm__ volatile ("rdinstret %0" : "=r"(instns_end));

	if (verbose)
	{
		print("Cycles: 0x");
		print_hex(cycles_end - cycles_begin, 8);
		putchar('\n');

		print("Instns: 0x");
		print_hex(instns_end - instns_begin, 8);
		putchar('\n');

		print("Chksum: 0x");
		print_hex(x32, 8);
		putchar('\n');
	}

	if (instns_p)
		*instns_p = instns_end - instns_begin;

	return cycles_end - cycles_begin;
}

// --------------------------------------------------------

#ifdef HX8KDEMO
void cmd_benchmark_all()
{
	uint32_t instns = 0;

	print("default        ");
	reg_spictrl = (reg_spictrl & ~0x00700000) | 0x00000000;
	print(": ");
	print_hex(cmd_benchmark(false, &instns), 8);
	putchar('\n');

	for (int i = 8; i > 0; i--)
	{
		print("dspi-");
		print_dec(i);
		print("         ");

		set_flash_latency(i);
		reg_spictrl = (reg_spictrl & ~0x00700000) | 0x00400000;

		print(": ");
		print_hex(cmd_benchmark(false, &instns), 8);
		putchar('\n');
	}

	for (int i = 8; i > 0; i--)
	{
		print("dspi-crm-");
		print_dec(i);
		print("     ");

		set_flash_latency(i);
		reg_spictrl = (reg_spictrl & ~0x00700000) | 0x00500000;

		print(": ");
		print_hex(cmd_benchmark(false, &instns), 8);
		putchar('\n');
	}

	for (int i = 8; i > 0; i--)
	{
		print("qspi-");
		print_dec(i);
		print("         ");

		set_flash_latency(i);
		reg_spictrl = (reg_spictrl & ~0x00700000) | 0x00200000;

		print(": ");
		print_hex(cmd_benchmark(false, &instns), 8);
		putchar('\n');
	}

	for (int i = 8; i > 0; i--)
	{
		print("qspi-crm-");
		print_dec(i);
		print("     ");

		set_flash_latency(i);
		reg_spictrl = (reg_spictrl & ~0x00700000) | 0x00300000;

		print(": ");
		print_hex(cmd_benchmark(false, &instns), 8);
		putchar('\n');
	}

	for (int i = 8; i > 0; i--)
	{
		print("qspi-ddr-");
		print_dec(i);
		print("     ");

		set_flash_latency(i);
		reg_spictrl = (reg_spictrl & ~0x00700000) | 0x00600000;

		print(": ");
		print_hex(cmd_benchmark(false, &instns), 8);
		putchar('\n');
	}

	for (int i = 8; i > 0; i--)
	{
		print("qspi-ddr-crm-");
		print_dec(i);
		print(" ");

		set_flash_latency(i);
		reg_spictrl = (reg_spictrl & ~0x00700000) | 0x00700000;

		print(": ");
		print_hex(cmd_benchmark(false, &instns), 8);
		putchar('\n');
	}

	print("instns         : ");
	print_hex(instns, 8);
	putchar('\n');
}
#endif

#ifdef ICEBREAKER
void cmd_benchmark_all()
{
	uint32_t instns = 0;

	print("default   ");
	set_flash_mode_spi();
	print_hex(cmd_benchmark(false, &instns), 8);
	putchar('\n');

	print("dual      ");
	set_flash_mode_dual();
	print_hex(cmd_benchmark(false, &instns), 8);
	putchar('\n');

	// print("dual-crm  ");
	// enable_flash_crm();
	// print_hex(cmd_benchmark(false, &instns), 8);
	// putchar('\n');

	print("quad      ");
	set_flash_mode_quad();
	print_hex(cmd_benchmark(false, &instns), 8);
	putchar('\n');

	print("quad-crm  ");
	enable_flash_crm();
	print_hex(cmd_benchmark(false, &instns), 8);
	putchar('\n');

	print("qddr      ");
	set_flash_mode_qddr();
	print_hex(cmd_benchmark(false, &instns), 8);
	putchar('\n');

	print("qddr-crm  ");
	enable_flash_crm();
	print_hex(cmd_benchmark(false, &instns), 8);
	putchar('\n');

}
#endif

// --------------------------------------------------------

void main()
{
	reg_leds = 31;
	reg_uart_clkdiv = 104;
	print("Booting..\n");

	reg_leds = 63;
	set_flash_qspi_flag();

	reg_leds = 127;
	while (getchar_prompt("Press ENTER to continue..\n") != '\r') { /* wait */ }

	print("\n");
	print("  ____  _          ____         ____\n");
	print(" |  _ \\(_) ___ ___/ ___|  ___  / ___|\n");
	print(" | |_) | |/ __/ _ \\___ \\ / _ \\| |\n");
	print(" |  __/| | (_| (_) |__) | (_) | |___\n");
	print(" |_|   |_|\\___\\___/____/ \\___/ \\____|\n");
	print("\nRunning on the Alhambra II board :-)\n");

	while (1)
	{
		print("\n");
		print("\n");
		print("SPI State:\n");

		print("  LATENCY ");
		print_dec((reg_spictrl >> 16) & 15);
		print("\n");

		print("  DDR ");
		if ((reg_spictrl & (1 << 22)) != 0)
			print("ON\n");
		else
			print("OFF\n");

		print("  QSPI ");
		if ((reg_spictrl & (1 << 21)) != 0)
			print("ON\n");
		else
			print("OFF\n");

		print("  CRM ");
		if ((reg_spictrl & (1 << 20)) != 0)
			print("ON\n");
		else
			print("OFF\n");

		print("\n");
		print("Select an action:\n");
		print("\n");
		print("   [1] Read SPI Flash ID\n");
		print("   [2] Read SPI Config Regs\n");
		print("   [3] Switch to default mode\n");
		print("   [4] Switch to Dual I/O mode\n");
		print("   [5] Switch to Quad I/O mode\n");
		print("   [6] Switch to Quad DDR mode\n");
		print("   [7] Toggle continuous read mode\n");
		print("   [9] Run simplistic benchmark\n");
		print("   [0] Benchmark all configs\n");
		print("\n");

		for (int rep = 10; rep > 0; rep--)
		{
			print("Command> ");
			char cmd = getchar();
			if (cmd > 32 && cmd < 127)
				putchar(cmd);
			print("\n");

			switch (cmd)
			{
			case '1':
				cmd_read_flash_id();
				break;
			case '2':
				cmd_read_flash_regs();
				break;
			case '3':
				set_flash_mode_spi();
				break;
			case '4':
				set_flash_mode_dual();
				break;
			case '5':
				set_flash_mode_quad();
				break;
			case '6':
				set_flash_mode_qddr();
				break;
			case '7':
				reg_spictrl = reg_spictrl ^ 0x00100000;
				break;
			case '9':
				cmd_benchmark(true, 0);
				break;
			case '0':
				cmd_benchmark_all();
				break;
			default:
				continue;
			}

			break;
		}
	}
}

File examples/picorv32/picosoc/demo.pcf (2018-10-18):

# -----------------------------------------------------------------------------
#- Alhambra II constraint file (.pcf)
#- By Juan Gonzalez (Obijuan) and Jesus Arroyo Torrens
#- May - 2018
#- GPL license
#- Repo: https://github.com/FPGAwars/Alhambra-II-FPGA
# -----------------------------------------------------------------------------


# ------------ User Leds ------------------------------------------------------
set_io --warn-no-port leds[0] 45  # output()
set_io --warn-no-port leds[1] 44 # output
set_io --warn-no-port leds[2] 43 # output
set_io --warn-no-port leds[3] 42 # output
set_io --warn-no-port leds[4] 41 # output
set_io --warn-no-port leds[5] 39 # output
set_io --warn-no-port leds[6] 38 # output
set_io --warn-no-port leds[7] 37 # output

# -------------------------- SYSTEM CLOCK -------------------------------------
set_io --warn-no-port clk 49  # input

# --- Flash memory (SPI)
set_io --warn-no-port flash_csb   71  # output (SS)
set_io --warn-no-port flash_io1   68  # input (MISO)
set_io --warn-no-port flash_io0   67  # output (MOSI)
set_io --warn-no-port flash_clk   70  # output (SCK)
#
# --- FTDI 1: (Serial port)
set_io --warn-no-port ser_tx  61  # output (ser-tx)
set_io --warn-no-port ser_rx  62  # input (ser-rx)

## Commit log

2018-08-08 User-test circuit added
2018-10-18 Initial example of picorv32 running on the Alhambra II board
2018-11-15 Uploaded Alhambra II v1.0A sources
    [Alhambra_II.PrjPcb, [1]_Alhambra_II.SchDoc, [2]_FPGA.SchDoc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]
2018-11-15 Schematics and designators
2019-04-26 Alhambra user test circuit updated
2019-04-26 Alhambra user test circuito updated
2019-05-20 user-test circuit updated: no verilog files requiered
